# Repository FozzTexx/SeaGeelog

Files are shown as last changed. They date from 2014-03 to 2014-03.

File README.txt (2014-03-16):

SeaGeelog: CGA/RGBI to analog converter board
Copyright 2014 by Chris Osborn
http://insentricity.com/a.cl/219

This work is licensed under a Creative Commons Attribution-ShareAlike
4.0 International License.
http://creativecommons.org/licenses/by-sa/4.0/

This circuit is designed to convert a standard TTL level CGA/RGBI
signal to analog RGB voltages. I have tested it with the output from
my Commodore 128. It does *not* do any scan doubling or conversion to
VGA frequences. The output will still be at the CGA/RGBI frequencies
which works with old Apple or arcade monitors. I'm using a GBS-8200
clone to convert the SeaGeelog output to a VGA signal.

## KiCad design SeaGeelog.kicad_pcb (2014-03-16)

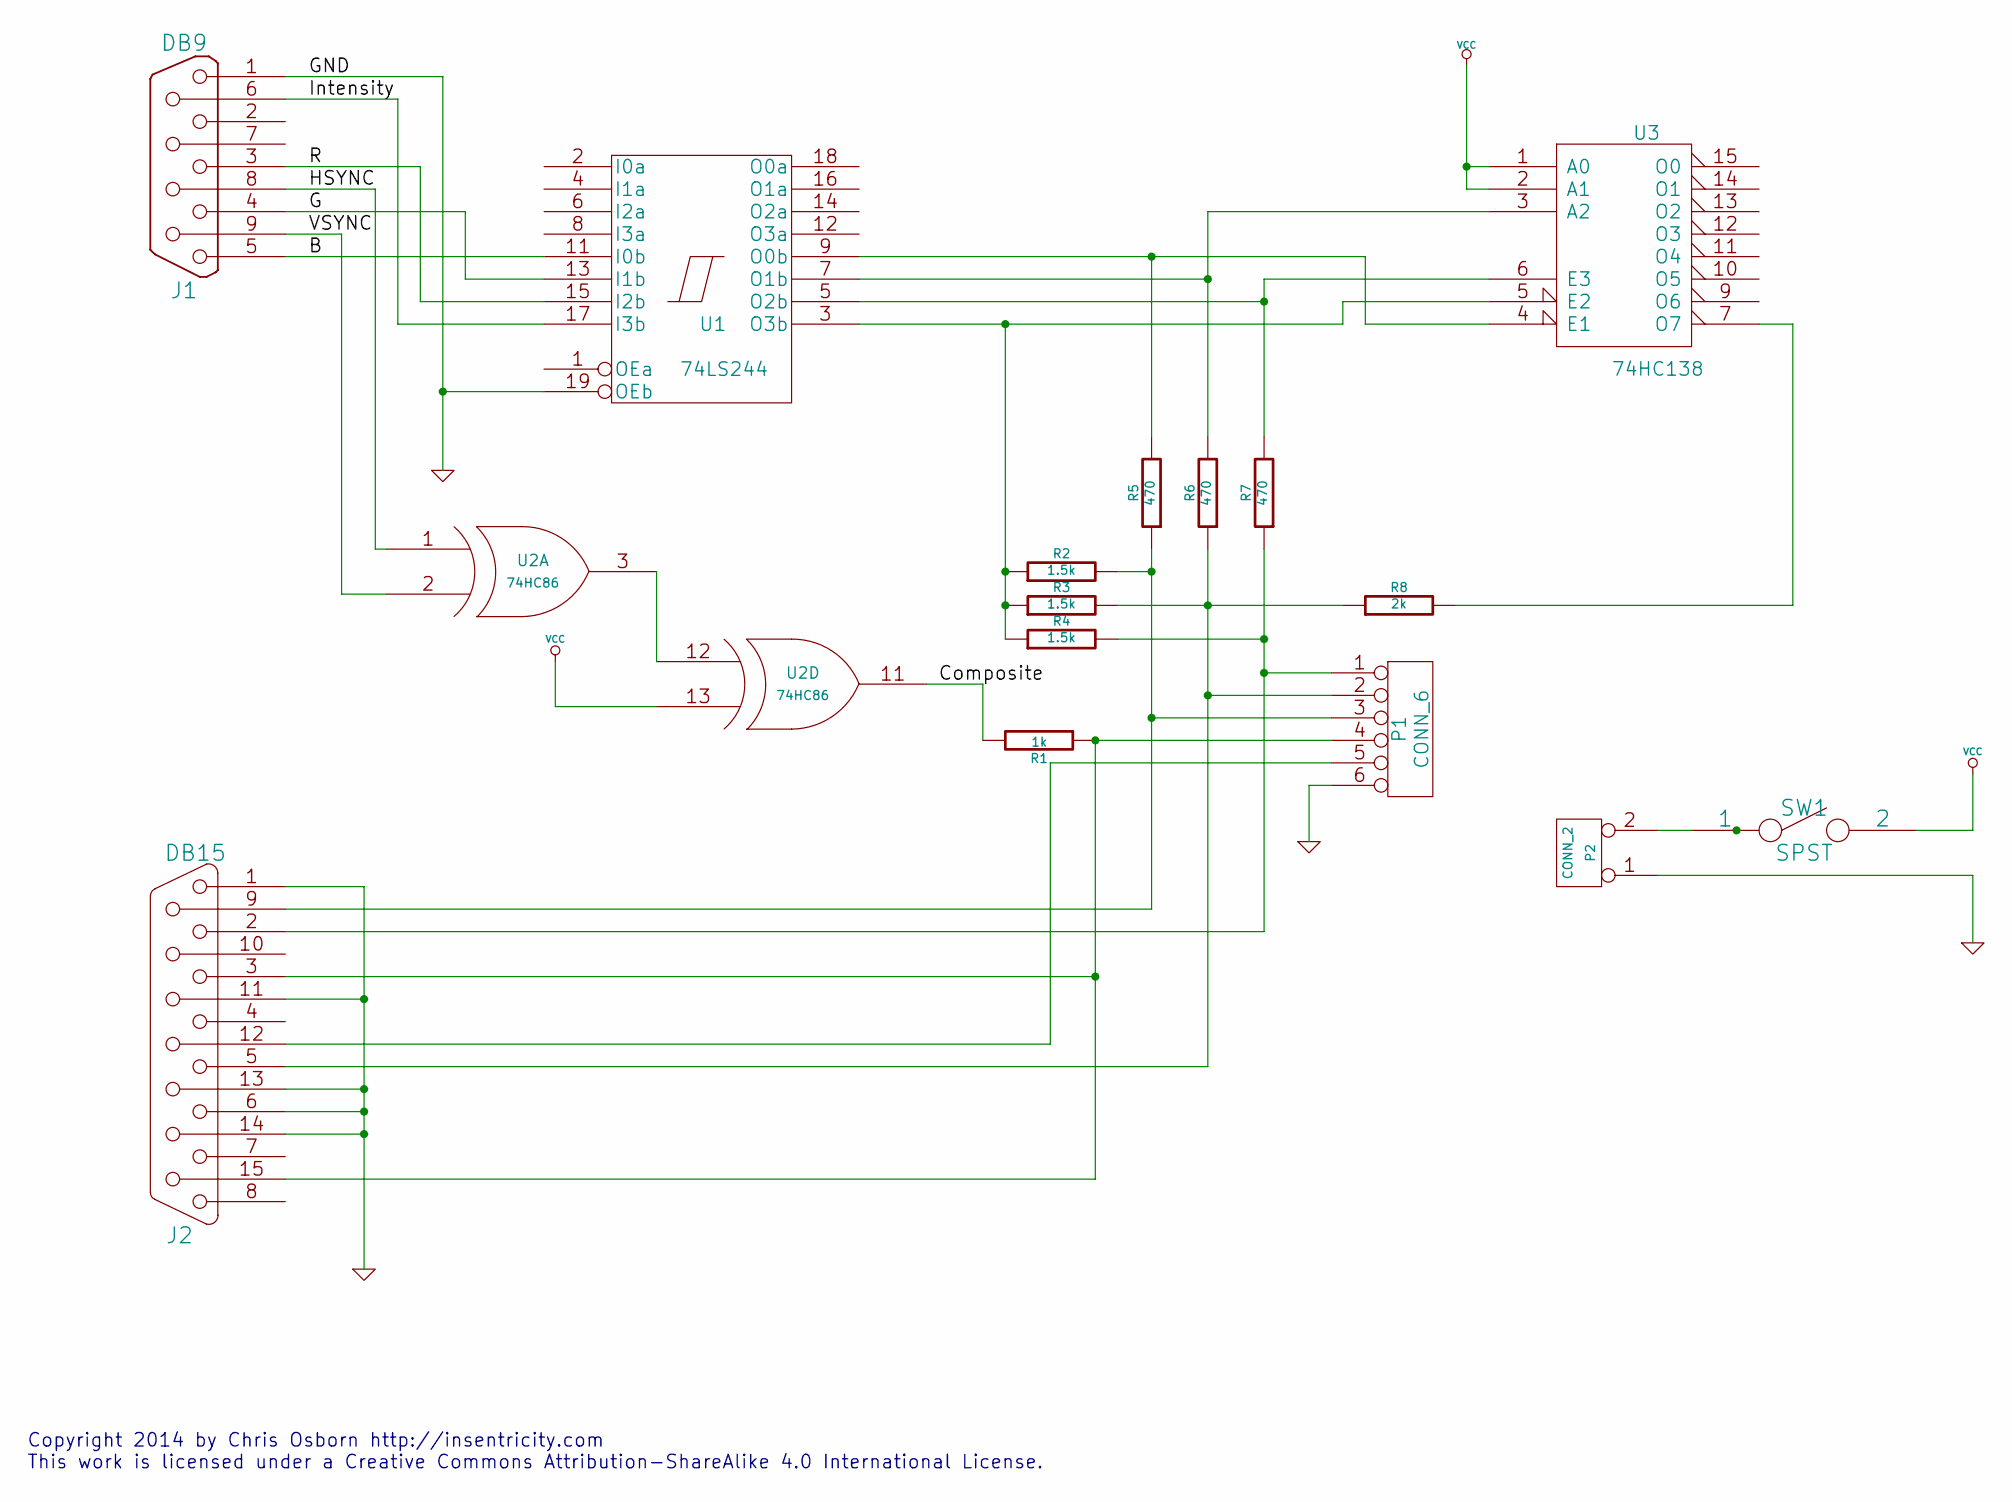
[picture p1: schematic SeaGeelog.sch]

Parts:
J1: DB9
J2: DB15
P1: CONN_6
P2: CONN_2
R1: 1k
R2, R3, R4: 1.5k
R5, R6, R7: 470
R8: 2k
SW1: SPST
U1: 74LS244
U2: 74HC86
U3: 74HC138

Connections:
/B: J1.5, U1.11 (I0b)
/Composite: R1.2, U2.11 (OUT)
/G: J1.4, U1.13 (I1b)
/HSYNC: J1.8, U2.1 (IN1)
/Intensity: J1.6, U1.17 (I3b)
/R: J1.3, U1.15 (I2b)
/VSYNC: J1.9, U2.2 (IN2)
GND: J1.1, J2.1, J2.6, J2.11 (P111), J2.13, J2.14, P1.6, P2.1, U1.10 (GND), U1.19 (OEb), U2.7 (GND), U3.8 (GND)
unnamed: J2.3, J2.15, P1.4, R1.1
unnamed: J2.12, P1.5
unnamed: J2.2, P1.1, R4.2, R7.1
unnamed: R8.2, U3.7 (O7)
unnamed: J2.9, P1.3, R2.2, R5.1
unnamed: J2.5, P1.2, R3.2, R6.1, R8.1
unnamed: P2.2 (PM), SW1.1
unnamed: U2.3 (OUT), U2.12 (IN1)
unnamed: R7.2, U1.5 (O2b), U3.6 (E3)
unnamed: R6.2, U1.7 (O1b), U3.3 (A2)
unnamed: R5.2, U1.9 (O0b), U3.4 (E1)
unnamed: R2.1, R3.1, R4.1, U1.3 (O3b), U3.5 (E2)
VCC: SW1.2, U1.20 (VCC), U2.13 (IN2), U2.14 (VCC), U3.1 (A0), U3.2 (A1), U3.16 (VCC)

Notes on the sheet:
Copyright 2014 by Chris Osborn http://insentricity.com This work is licensed under a Creative Commons Attribution-ShareAlike 4.0 International License.

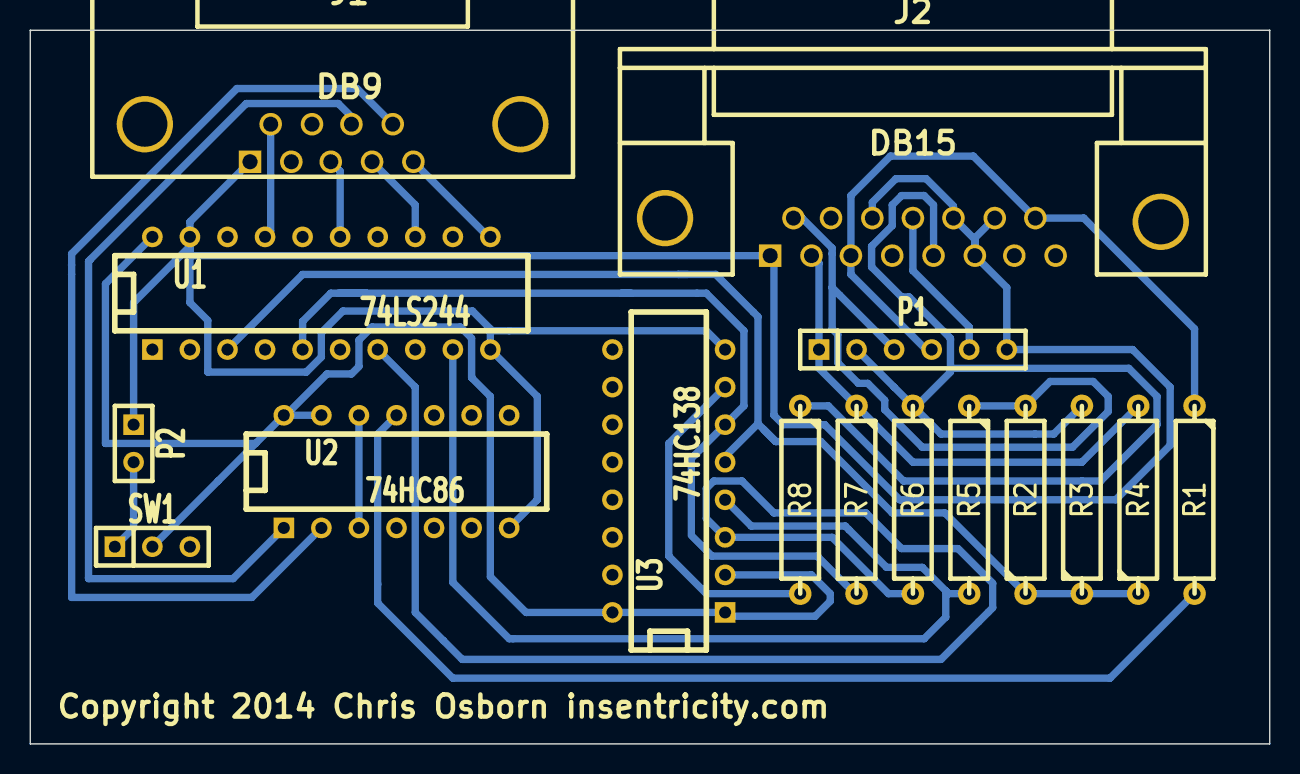
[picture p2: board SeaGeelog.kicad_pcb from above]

Board: 2 copper layers, 83.8 x 48.3 mm, 16 parts (0 on the bottom side), 21 nets.

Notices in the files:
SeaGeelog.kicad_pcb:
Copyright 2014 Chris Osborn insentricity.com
